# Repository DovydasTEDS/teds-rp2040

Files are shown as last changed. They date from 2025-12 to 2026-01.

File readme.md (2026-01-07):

# TEDS RP2040

an rp2040 devboard. GPIO pinouts should be the same as / similar to the pi pico, with a few extra pins  
there is also an LED which could be used as a status indicator  

routing the PCB was a pain... especially since the footprint for the flash was bigger than the easy EasyRP2040 guide  
both usb routes are the same distance like required  

Schematic            |  PCB         |   PCB (3d)
:-------------------------:|:-------------------------:|:-------------------------:|
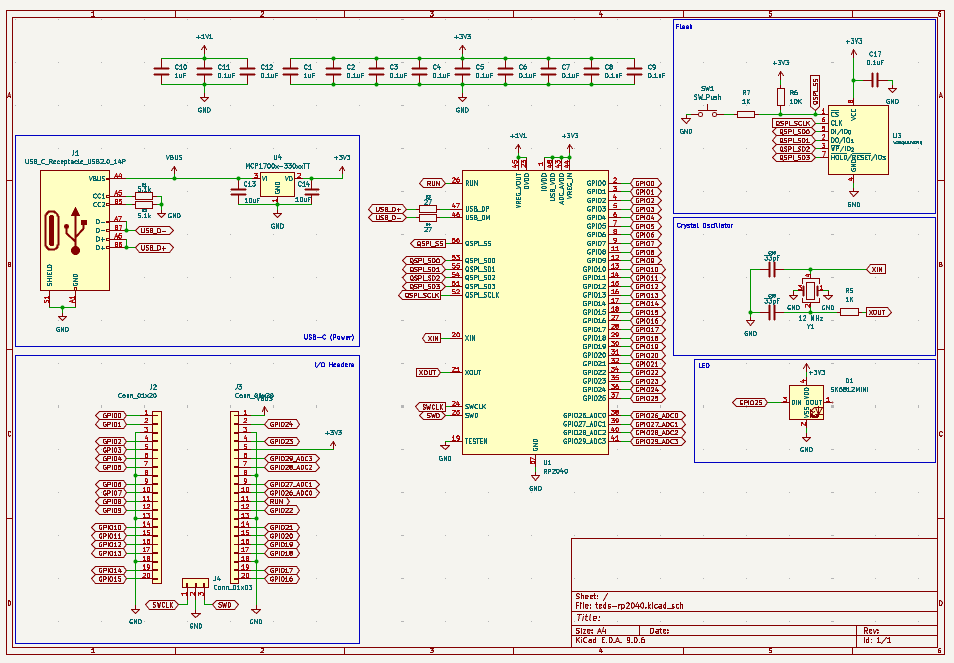
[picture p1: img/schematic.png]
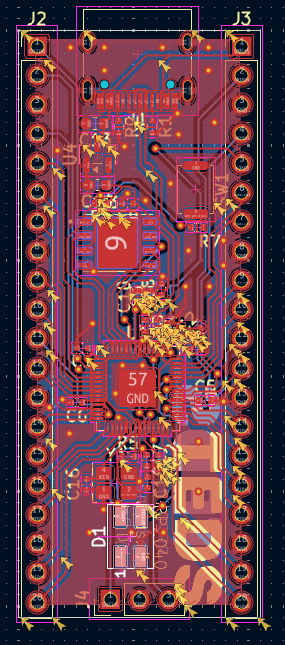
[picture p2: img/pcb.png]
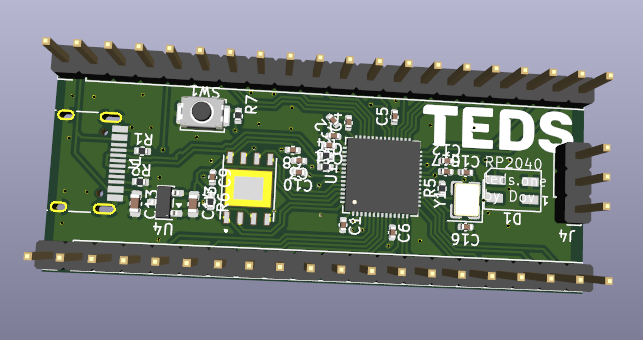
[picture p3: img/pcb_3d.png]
    |    |

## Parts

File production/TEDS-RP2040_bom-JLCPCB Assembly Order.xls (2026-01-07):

JLCPCB BOM Tool - BOM Matching
BOM name：TEDS-RP2040_bom-JLCPCB Assembly Order.xlsx |  |  | Download Time：2026-01-08 02:59:17 |  |  |  | * Our matching results are updated in real-time, but stock and prices may change. If it's been over 24 hours, please re-match before placing your order.
PCB Assembled Qty：5 |  |  | Est. Total Price：6.9473
Your BOM |  |  |  |  | Matched Parts |  |  |  |  |  |  | Order Information
Top Designator | Bottom Designator | Comment | Footprint | JLCPCB Part # | Matches | Part # | Manufacturer | Footprint | Description | Category | Warning | JLCPCB Part # | Product link | Lib Type | Qty | Source | Total Price ($)
C1,C10 |  | 1uF | 0402 |  | Select by System | CL05A105KA5NQNC | Samsung Electro-Mechanics | 0402 | 1uF 25V X5R ±10% 0402 Multilayer Ceramic Capacitors MLCC - SMD/SMT ROHS | Multilayer Ceramic Capacitors MLCC - SMD/SMT |  | C52923 | https://jlcpcb.com/partdetail/53938-CL05A105KA5NQNC/C52923 | Basic | 4 | 4 JLCPCB | 0.012
C11,C12,C17,C2,C3,C4,C5,C6,C7,C8,C9 |  | 0.1uF | 0402 |  | Unconfirmed | CL05B104KO5NNNC | Samsung Electro-Mechanics | 0402 | 100nF 16V X7R ±10% 0402 Multilayer Ceramic Capacitors MLCC - SMD/SMT ROHS | Multilayer Ceramic Capacitors MLCC - SMD/SMT | 1.The comment (CL05B104KO5NNNC) of this part does not match the one (0.1uF) provided in your BOM. Please confirm; | C1525 | https://jlcpcb.com/partdetail/1877-CL05B104KO5NNNC/C1525 | Basic | 22 | 22 JLCPCB | 0.0264
C13,C14 |  | 10uF | 0603 |  | Select by System | CL10A106KP8NNNC | Samsung Electro-Mechanics | 0603 | 10V 10uF X5R ±10% 0603 Multilayer Ceramic Capacitors MLCC - SMD/SMT ROHS | Multilayer Ceramic Capacitors MLCC - SMD/SMT |  | C19702 | https://jlcpcb.com/partdetail/20411-CL10A106KP8NNNC/C19702 | Basic | 4 | 4 JLCPCB | 0.0232
C15,C16 |  | 33pF | 0402 |  | Select by System | 0402CG330J500NT | FH (Guangdong Fenghua Advanced Tech) | 0402 | 33pF 50V C0G ±5% 0402 Multilayer Ceramic Capacitors MLCC - SMD/SMT ROHS | Multilayer Ceramic Capacitors MLCC - SMD/SMT |  | C1562 | https://jlcpcb.com/partdetail/1914-0402CG330J500NT/C1562 | Basic | 4 | 4 JLCPCB | 0.0044
D1 |  | SK6812MINI | LED_SK6812MINI_PLCC4_3.5x3.5mm_P1.75mm |  | Unconfirmed | SK6812MINI-E | OPSCO Optoelectronics | SMD | -40℃~+85℃ 0.6mA 1.78mm 120° 1kHz 2.8mm 2000V 3.2mm 3.7V~5.5V 800Kbit/s G:815mcd~1275mcd R:620nm~625nm Semi-transparent lens SMD RGB LEDs(Built-in IC) ROHS | RGB LEDs(Built-In IC) | 1.The comment (SK6812MINI-E) of this part does not match the one (SK6812MINI) provided in your BOM. Please confirm; | C5149201 | https://jlcpcb.com/partdetail/OPSCOOptoelectronics-SK6812MINIE/C5149201 | Extended | 0 | 0 JLCPCB | 0
J1 |  | USB_C_Receptacle_USB2.0_14P | USB_C_Receptacle_HRO_TYPE-C-31-M-12 |  | Select by Customer | TYPE-C-31-M-12 | Korean Hroparts Elec | SMD | -30℃~+80℃ 1 10,000 cycles 16P 20V 5A 7.35mm Female Surface Mount, Right Angle Type-C SMD USB Connectors ROHS | USB Connectors |  | C165948 | https://jlcpcb.com/partdetail/Korean_HropartsElec-TYPE_C_31_M12/C165948 | Extended | 2 | 2 JLCPCB | 0.353
R1,R2 |  | 5.1k | 0402 |  | Unconfirmed | 0402WGF5101TCE | UNI-ROYAL(Uniroyal Elec) | 0402 | -55℃~+155℃ 5.1kΩ 50V 62.5mW Thick Film Resistor ±1% ±100ppm/℃ 0402 Chip Resistor - Surface Mount ROHS | Chip Resistor - Surface Mount | 1.The comment (0402WGF5101TCE) of this part does not match the one (5.1k) provided in your BOM. Please confirm; | C25905 | https://jlcpcb.com/partdetail/26648-0402WGF5101TCE/C25905 | Basic | 4 | 4 JLCPCB | 0.0024
R3,R4 |  | 27 | 0402 |  | Unconfirmed | 0402WGF270JTCE | UNI-ROYAL(Uniroyal Elec) | 0402 | -55℃~+155℃ 27Ω 50V 62.5mW Thick Film Resistor ±1% ±100ppm/℃ 0402 Chip Resistor - Surface Mount ROHS | Chip Resistor - Surface Mount | 1.The comment (0402WGF270JTCE) of this part does not match the one (27) provided in your BOM. Please confirm; | C25100 | https://jlcpcb.com/partdetail/25843-0402WGF270JTCE/C25100 | Extended | 20 | 20 JLCPCB | 0.012
R5,R7 |  | 1K | 0402 |  | Unconfirmed | 0402WGF1001TCE | UNI-ROYAL(Uniroyal Elec) | 0402 | -55℃~+155℃ 1kΩ 50V 62.5mW Thick Film Resistor ±1% ±100ppm/℃ 0402 Chip Resistor - Surface Mount ROHS | Chip Resistor - Surface Mount | 1.The comment (0402WGF1001TCE) of this part does not match the one (1K) provided in your BOM. Please confirm; | C11702 | https://jlcpcb.com/partdetail/12256-0402WGF1001TCE/C11702 | Basic | 4 | 4 JLCPCB | 0.0024
R6 |  | 10K | 0402 |  | Unconfirmed | 0402WGF1002TCE | UNI-ROYAL(Uniroyal Elec) | 0402 | -55℃~+155℃ 10kΩ 50V 62.5mW Thick Film Resistor ±1% ±100ppm/℃ 0402 Chip Resistor - Surface Mount ROHS | Chip Resistor - Surface Mount | 1.The comment (0402WGF1002TCE) of this part does not match the one (10K) provided in your BOM. Please confirm; | C25744 | https://jlcpcb.com/partdetail/26487-0402WGF1002TCE/C25744 | Basic | 2 | 2 JLCPCB | 0.0012
SW1 |  | SW_Push | SW_Push_SPST_NO_Alps_SKRK |  | Select by Customer | TS-1088-AR02016 | XUNPU | SMD,4x3mm | -30℃~+80℃ 1.6N 100,000 Cycles 12V 2mm 3mm 4mm 50mA Black Round Button SMD(SMT) Tab SPST Surface Mount,Vertical Without Bracket SMD,4x3mm Tactile Switches ROHS | Tactile Switches |  | C720477 | https://jlcpcb.com/partdetail/XUNPU-TS_1088AR02016/C720477 | Basic | 2 | 2 JLCPCB | 0.0886
U1 |  | RP2040 | QFN-56-1EP_7x7mm_P0.4mm_EP3.2x3.2mm |  | Select by Customer | RP2040 | Raspberry Pi | LQFN-56(7x7) | 12bit 133MHz 30 LQFN-56(7x7) Microcontrollers (MCU/MPU/SOC) ROHS | Microcontrollers (MCU/MPU/SOC) |  | C2040 | https://jlcpcb.com/partdetail/RaspberryPi-RP2040/C2040 | Extended | 2 | 2 JLCPCB | 1.9098
U3 |  | W25Q16JVZPIQ | SON127P500X600X80-9N |  | Select by System | W25Q16JVZPIQ | Winbond Elec | WSON-8(5x6) | -40℃~+85℃ 0.2uA 100,000 Cycles 120ms@(32KB) 133MHz 16Mbit 2.7V~3.6V 20 Years 3ms SPI WSON-8(5x6) NOR FLASH ROHS | NOR FLASH |  | C377853 | https://jlcpcb.com/partdetail/WinbondElec-W25Q16JVZPIQ/C377853 | Extended | 2 | 2 JLCPCB | 1.5224
U4 |  | MCP1700x-330xxTT | SOT-23 |  | Select by Customer | MCP1700T-3302E/TT | Microchip Tech | SOT-23 | -40℃~+125℃@(Tj) 1 1.6uA 178mV@(250mA) 250mA 3.3V 44dB@(100Hz) 6V Fixed Over Temperature Protection Positive SOT-23 Voltage Regulators - Linear, Low Drop Out (LDO) Regulators ROHS | Voltage Regulators - Linear, Low Drop Out (LDO) Regulators |  | C39051 | https://jlcpcb.com/partdetail/MicrochipTech-MCP1700T_3302ETT/C39051 | Extended | 5 | 5 JLCPCB | 1.7865
Y1 |  | 12MHz | Crystal_SMD_3225-4Pin_3.2x2.5mm |  | Select by System | NX3225GA-12MHZ-STD-CRG-2 | NDK | SMD3225-4P | -40℃~+85℃ 100Ω 12MHz 8pF ±20ppm ±30ppm SMD3225-4P Crystals ROHS | Crystals |  | C481407 | https://jlcpcb.com/partdetail/NDK-NX3225GA_12MHZ_STD_CRG2/C481407 | Extended | 5 | 5 JLCPCB | 1.203
J2,J3 |  | Conn_01x20 | PinHeader_1x20_P2.54mm_Vertical |  | No matches | No Part Selected
J4 |  | Conn_01x03 | PinHeader_1x03_P2.54mm_Vertical |  | No matches | No Part Selected

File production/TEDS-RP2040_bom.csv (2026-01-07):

Designator | Footprint | Quantity | Value | LCSC Part #
C1, C10 | 0402 | 2 | 1uF
C11, C12, C17, C2, C3, C4, C5, C6, C7, C8, C9 | 0402 | 11 | 0.1uF
C13, C14 | 0603 | 2 | 10uF
C15, C16 | 0402 | 2 | 33pF
D1 | LED_SK6812MINI_PLCC4_3.5x3.5mm_P1.75mm | 1 | SK6812MINI
J1 | USB_C_Receptacle_HRO_TYPE-C-31-M-12 | 1 | USB_C_Receptacle_USB2.0_14P
J2, J3 | PinHeader_1x20_P2.54mm_Vertical | 2 | Conn_01x20
J4 | PinHeader_1x03_P2.54mm_Vertical | 1 | Conn_01x03
R1, R2 | 0402 | 2 | 5.1k
R3, R4 | 0402 | 2 | 27
R5, R7 | 0402 | 2 | 1K
R6 | 0402 | 1 | 10K
SW1 | SW_Push_SPST_NO_Alps_SKRK | 1 | SW_Push
U1 | QFN-56-1EP_7x7mm_P0.4mm_EP3.2x3.2mm | 1 | RP2040
U3 | SON127P500X600X80-9N | 1 | W25Q16JVZPIQ
U4 | SOT-23 | 1 | MCP1700x-330xxTT
Y1 | Crystal_SMD_3225-4Pin_3.2x2.5mm | 1 | 12 MHz

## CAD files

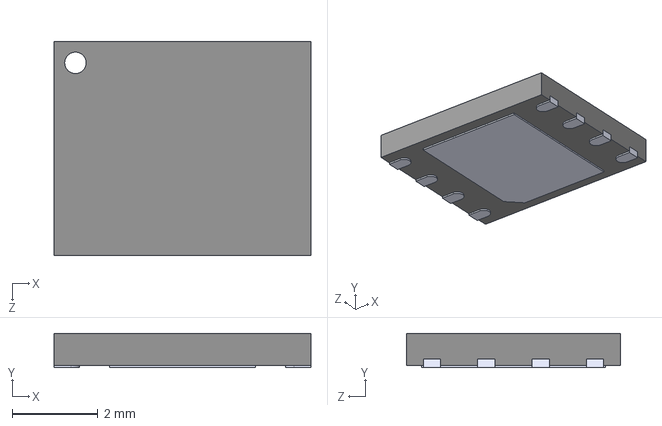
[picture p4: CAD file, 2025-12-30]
pcb/teds-rp2040/W25Q16JVZPIQ/W25Q16JVZPIQ.step
6.00 x 0.8 x 5.00 mm

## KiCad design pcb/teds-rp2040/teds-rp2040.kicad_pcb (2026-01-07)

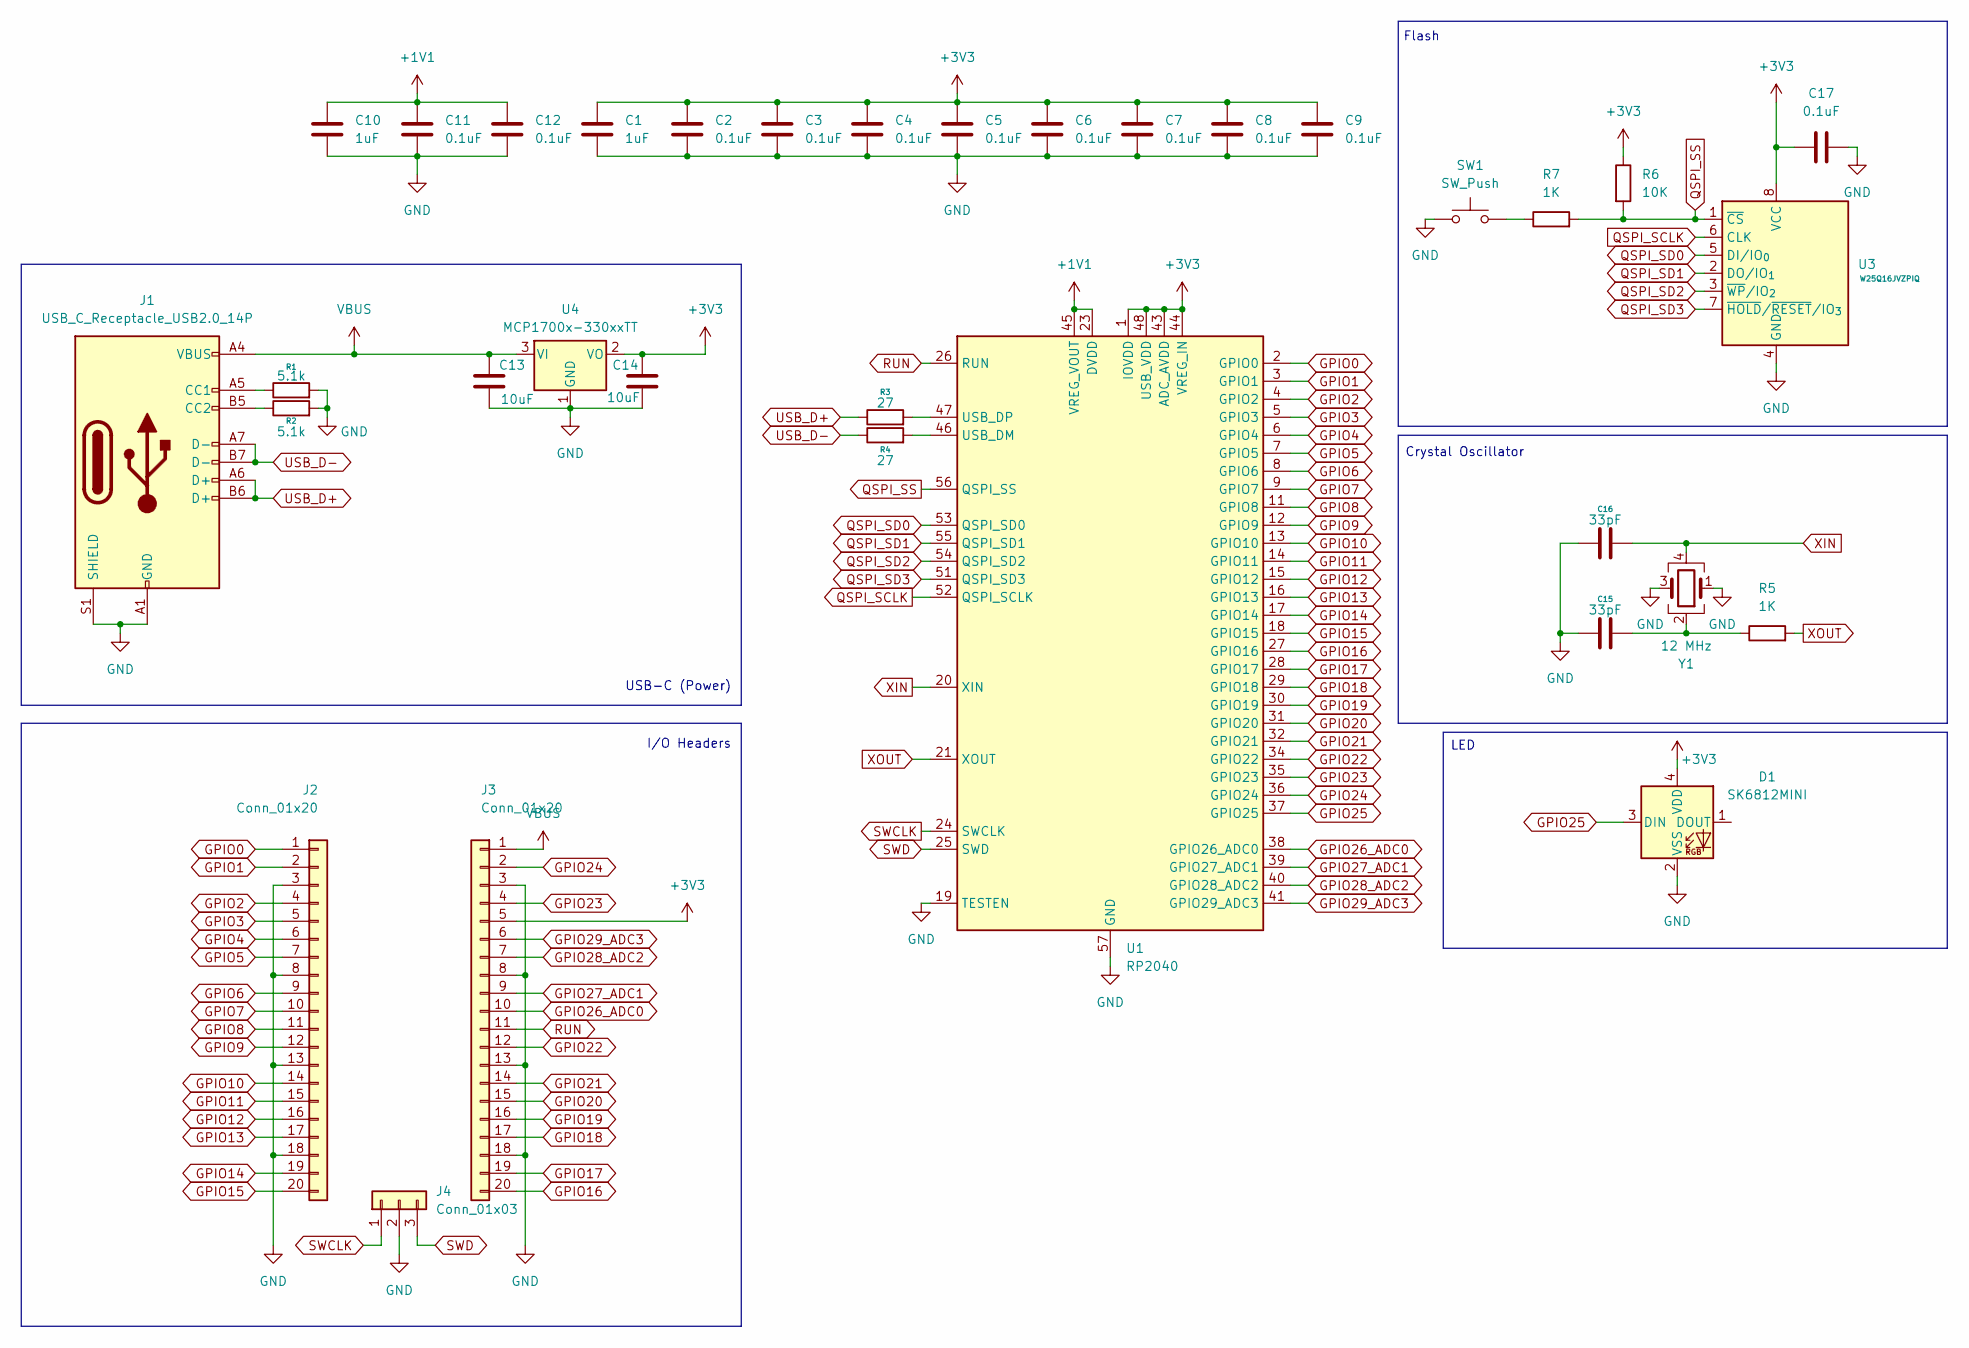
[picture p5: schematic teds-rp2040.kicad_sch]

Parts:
C1, C10: 1uF; C_0402_1005Metric
C2, C3, C4, C5, C6, C7, C8, C9, C11, C12, C17: 0.1uF; C_0402_1005Metric
C13, C14: 10uF; C_0603_1608Metric
C15, C16: 33pF; C_0402_1005Metric
D1: SK6812MINI; LED_SK6812MINI_PLCC4_3.5x3.5mm_P1.75mm
J1: USB_C_Receptacle_USB2.0_14P; USB_C_Receptacle_HRO_TYPE-C-31-M-12
J2, J3: Conn_01x20; PinHeader_1x20_P2.54mm_Vertical
J4: Conn_01x03; PinHeader_1x03_P2.54mm_Vertical
R1, R2: 5.1k; R_0402_1005Metric
R3, R4: 27; R_0402_1005Metric
R5, R7: 1K; R_0402_1005Metric
R6: 10K; R_0402_1005Metric
SW1: SW_Push; SW_Push_SPST_NO_Alps_SKRK
U1: RP2040; QFN-56-1EP_7x7mm_P0.4mm_EP3.2x3.2mm
U3: W25Q16JVZPIQ; SON127P500X600X80-9N
U4: MCP1700x-330xxTT; SOT-23
Y1: 12 MHz; Crystal_SMD_3225-4Pin_3.2x2.5mm

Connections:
+1V1: C10.1, C11.1, C12.1, U1.23 (DVDD), U1.45 (VREG_VOUT), U1.50 (DVDD)
+3V3: C1.1, C2.1, C3.1, C4.1, C5.1, C6.1, C7.1, C8.1, C9.1, C14.1, C17.1, D1.4 (VDD), J3.5, R6.1, U1.1 (IOVDD), U1.10 (IOVDD), U1.22 (IOVDD), U1.33 (IOVDD), U1.42 (IOVDD), U1.43 (ADC_AVDD), U1.44 (VREG_IN), U1.48 (USB_VDD), U1.49 (IOVDD), U3.8 (VCC), U4.2 (VO)
GND: C1.2, C2.2, C3.2, C4.2, C5.2, C6.2, C7.2, C8.2, C9.2, C10.2, C11.2, C12.2, C13.2, C14.2, C15.1, C16.1, C17.2, D1.2 (VSS), J1.A1 (GND), J1.A12 (GND), J1.B1 (GND), J1.B12 (GND), J1.S1 (SHIELD), J2.3, J2.8, J2.13, J2.18, J3.3, J3.8, J3.13, J3.18, J4.2, R1.2, R2.2, SW1.1, U1.19 (TESTEN), U1.57 (GND), U3.4 (GND), U4.1 (GND), Y1.1, Y1.3
GPIO0: J2.1, U1.2 (GPIO0)
GPIO1: J2.2, U1.3 (GPIO1)
GPIO2: J2.4, U1.4 (GPIO2)
GPIO3: J2.5, U1.5 (GPIO3)
GPIO4: J2.6, U1.6 (GPIO4)
GPIO5: J2.7, U1.7 (GPIO5)
GPIO6: J2.9, U1.8 (GPIO6)
GPIO7: J2.10, U1.9 (GPIO7)
GPIO8: J2.11, U1.11 (GPIO8)
GPIO9: J2.12, U1.12 (GPIO9)
GPIO10: J2.14, U1.13 (GPIO10)
GPIO11: J2.15, U1.14 (GPIO11)
GPIO12: J2.16, U1.15 (GPIO12)
GPIO13: J2.17, U1.16 (GPIO13)
GPIO14: J2.19, U1.17 (GPIO14)
GPIO15: J2.20, U1.18 (GPIO15)
GPIO16: J3.20, U1.27 (GPIO16)
GPIO17: J3.19, U1.28 (GPIO17)
GPIO18: J3.17, U1.29 (GPIO18)
GPIO19: J3.16, U1.30 (GPIO19)
GPIO20: J3.15, U1.31 (GPIO20)
GPIO21: J3.14, U1.32 (GPIO21)
GPIO22: J3.12, U1.34 (GPIO22)
GPIO23: J3.4, U1.35 (GPIO23)
GPIO24: J3.2, U1.36 (GPIO24)
GPIO25: D1.3 (DIN), U1.37 (GPIO25)
GPIO26_ADC0: J3.10, U1.38 (GPIO26_ADC0)
GPIO27_ADC1: J3.9, U1.39 (GPIO27_ADC1)
GPIO28_ADC2: J3.7, U1.40 (GPIO28_ADC2)
GPIO29_ADC3: J3.6, U1.41 (GPIO29_ADC3)
unnamed: C15.2, R5.1, Y1.2
unnamed: J1.A5 (CC1), R1.1
unnamed: J1.B5 (CC2), R2.1
unnamed: R7.1, SW1.2
unnamed: R4.2, U1.46 (USB_DM)
unnamed: R3.2, U1.47 (USB_DP)
QSPI_SCLK: U1.52 (QSPI_SCLK), U3.6 (CLK)
QSPI_SD0: U1.53 (QSPI_SD0), U3.5 (DI/IO_{0})
QSPI_SD1: U1.55 (QSPI_SD1), U3.2 (DO/IO_{1})
QSPI_SD2: U1.54 (QSPI_SD2), U3.3 (~WP/IO_{2})
QSPI_SD3: U1.51 (QSPI_SD3), U3.7 (~HOLD/~RESET/IO_{3})
QSPI_SS: R6.2, R7.2, U1.56 (QSPI_SS), U3.1 (~CS)
RUN: J3.11, U1.26 (RUN)
SWCLK: J4.1, U1.24 (SWCLK)
SWD: J4.3, U1.25 (SWD)
USB_D+: J1.A6 (D+), J1.B6 (D+), R3.1
USB_D-: J1.A7 (D-), J1.B7 (D-), R4.1
VBUS: C13.1, J1.A4 (VBUS), J1.A9 (VBUS), J1.B4 (VBUS), J1.B9 (VBUS), J3.1, U4.3 (VI)
XIN: C16.2, U1.20 (XIN), Y1.4
XOUT: R5.2, U1.21 (XOUT)

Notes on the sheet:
LED
Crystal Oscillator
I/O Headers
USB-C (Power)
Flash

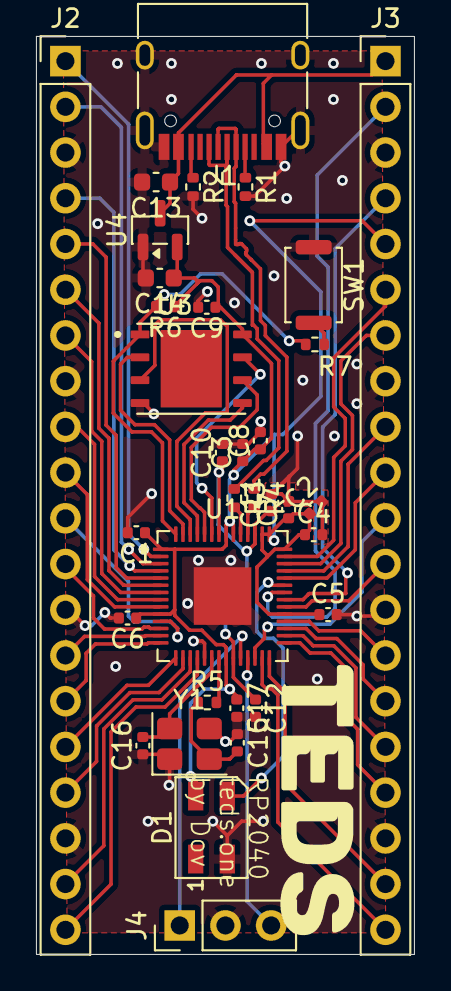
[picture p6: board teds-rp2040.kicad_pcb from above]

Board: 2 copper layers, 21.0 x 51.0 mm, 34 parts (0 on the bottom side), 53 nets.

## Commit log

2026-01-03 Make it work
    [teds-rp2040.kicad_pcb, teds-rp2040.kicad_sch]
2026-01-03 add BOM from jlcpcb
    [TEDS-RP2040_bom-JLCPCB Assembly Order.xls, TEDS-RP2040_bom.csv, TEDS-RP2040_designators.csv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]
2026-01-03 add production folder in project root
    [TEDS-RP2040_bom-JLCPCB Assembly Order.xls, TEDS-RP2040_bom.csv, TEDS-RP2040_positions.csv]
2026-01-07 add led
    [TEDS-RP2040_bom-JLCPCB Assembly Order.xls, TEDS-RP2040_bom.csv, TEDS-RP2040_designators.csv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]
